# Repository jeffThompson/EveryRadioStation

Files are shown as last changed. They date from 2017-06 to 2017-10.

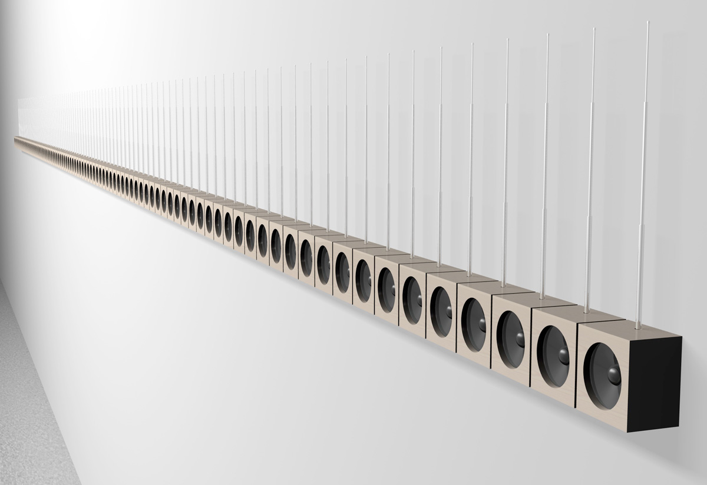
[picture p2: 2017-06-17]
Renderings/Mockup7-web.jpg

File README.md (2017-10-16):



# EVERY RADIO STATION

An installation of 95 software-defined FM radios, one for each station in the FM band, each playing simultaneously.

## CONTENTS  

* **CAD-Files:** PCB and lasercut files  
* **Datasheets:** For all important components in the piece  
* **Documentation:** Photo/video documentation  
* **EarlyVersions:** Roads-not-taken, broken things, and other early iterations  
* **Firmware:** Arduino firmware for communicating with the Si4703 radios over I2C  
* **Labels:** Stick-on labels for the back of the piece  
** LayoutDiagrams:** PDF and lasercut diagrams for placing all the parts  
* **Renderings:** Early renderings of how the piece would look and be displayed  
* **BOM:** List of materials used to build this piece  

Developed during a residency at [Wave Farm](https://wavefarm.org/) in Acra, New York, USA.

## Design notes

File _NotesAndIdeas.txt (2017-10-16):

NOTES && IDEAS

TODO

[ ] write up desc for website (already in db)

[X] design connections between boxes
[X] how to hang from wall?
[X] two power supplies, for stacked version?
	- or intermediary cord between them?
	- maybe could have separate box for power, make two
		- one with a single plug in the bottom
		- one with plug in bottom, connector on top?
[X] hole template for marking large speaker hole, smaller 
    mounting ones too
[X] figure out mounting holes for power supply
[X] how to mount PCBs to piece?
	- lasercut template
	- spraypaint to show area to use
	- foam tape to secure
	
- - -

95 total radios
- 12 per section, final section has 11
- covers 87.5–107.9
- should work everywhere except Japan and maybe Eastern Europe/Russia
- in Europe, bands may go by 100kHz inc instead of 200, so we might miss some
	- option in code to go odd (ie 99.1) or even (99.2) in case that's helpful

- - -

https://www.thingiverse.com/thing:683669/#comments

POWER SUPPLY – LS35 (3.3V)

L = live line in
N = neutral line in

should be at least 15mm (0.6") from anything on vent sides

- - -

https://learn.sparkfun.com/tutorials/si4703-fm-radio-receiver-hookup-guide

- - -

FM band from 87.5 - 107.9 MHz (in North America)
Separated by 2's on the odd numbers

87.5, 87.7, 87.9
- three stations

90.1, 90.3, 90.5, 90.7, 90.9
- five stations per block like this...

91, 92, 93, 94, 95, 96, 97, 98, 99, 100,
101, 102, 103, 104, 105, 106, 107
- 17 blocks of 5 = 85

Total number of possible FM radio stations:
3 + 5 + 85 = 93

+ #0
	0	875
	1	877
	2	879
	3	881
	4	883
	5	885
	6	887
	7	889

+ #1
	0	891
	1	893
	2	895
	3	897
	4	899
	5	901
	6	903
	7	905

+ #2
	0	907
	1	909
	2	911
	3	913
	4	915
	5	917
	6	919
	7	921

+ #3
	0	923
	1	925
	2	927
	3	929
	4	931
	5	933
	6	935
	7	937
	
+ #4
	0	939
	1	941
	2	943
	3	945
	4	947
	5	949
	6	951
	7	953

+ #5
	0	955
	1	957
	2	959
	3	961
	4	963
	5	965
	6	967
	7	969

+ #6
	0	971
	1	973
	2	975
	3	977
	4	979
	5	981
	6	983
	7	985

+ #7
	0	987
	1	989
	2	991
	3	993
	4	995
	5	997
	6	999
	7	1001

+ #8
	0	1003
	1	1005
	2	1007
	3	1009
	4	1011
	5	1013
	6	1015
	7	1017

+ #9
	0	1019
	1	1021
	2	1023
	3	1025
	4	1027
	5	1029
	6	1031
	7	1033
	0	1035
	1	1037

#10	
	2	1039
	3	1041
	4	1043
	5	1045
	6	1047
	7	1049
	0	1051
	1	1053

#11
	2	1055
	3	1057
	4	1059
	5	1061
	6	1063
	7	1065
	8	1067

oops
	7	1069
	0	1071
	1	1073
	2	1075
	3	1079

- - -

AM band from 535 - 1705 kHz (in North America)
Separated by 10's

535 (effectively 540), 550, 560, 570, 580, 590
- block of six stations

600, 700, 800, 900, 1000, 1100, 1200, 1300, 
1400, 1500, 1600
- 11 blocks of 10 stations = 1100

1705 (effectively (1700)
- last station

Total number of possible AM radio stations:
6 + 1100 + 1 = 1107

- - -

Total number of possible AM and FM radio stations in 
any given place in North America: 1,200

- https://www.sparkfun.com/products/12938
- http://www.silabs.com/Support%20Documents/TechnicalDocs/Si4831-35-B30.pdf
- possible SDR method: https://github.com/hpdvanwyk/fm-multimix
- https://github.com/kpreid/shinysdr

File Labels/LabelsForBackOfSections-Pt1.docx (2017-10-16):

Jeff Thompson Every Radio Station: Section 1 Wood, 95 FM radios, speakers, custom software 2017 Cleats: 27” between, 5” to next section (both on center) | | Jeff Thompson Every Radio Station: Section 2 Wood, 95 FM radios, speakers, custom software 2017 Cleats: 27” between, 5” to next section (both on center)
Jeff Thompson Every Radio Station: Section 3 Wood, 95 FM radios, speakers, custom software 2017 Cleats: 27” between, 5” to next section (both on center) | | Jeff Thompson Every Radio Station: Section 4 Wood, 95 FM radios, speakers, custom software 2017 Cleats: 27” between, 5” to next section (both on center)
Jeff Thompson Every Radio Station: Section 5 Wood, 95 FM radios, speakers, custom software 2017 Cleats: 27” between, 5” to next section (both on center) | | Jeff Thompson Every Radio Station: Section 6 Wood, 95 FM radios, speakers, custom software 2017 Cleats: 27” between, 5” to next section (both on center)

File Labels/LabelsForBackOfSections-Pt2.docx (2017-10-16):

Jeff Thompson Every Radio Station: Section 7 Wood, 95 FM radios, speakers, custom software 2017 Cleats: 27” between, 5” to next section (both on center) | | Jeff Thompson Every Radio Station: Section 8 Wood, 95 FM radios, speakers, custom software 2017 Cleats: 27” between, 5” to next section (both on center)
Jeff Thompson Every Radio Station: Section 9 Wood, 95 FM radios, speakers, custom software 2017 Cleats: 24” between, 5” to next section (both on center) | | Jeff Thompson Every Radio Station: Section 10 Wood, 95 FM radios, speakers, custom software 2017 Cleats: 27” between, 5” to next section (both on center)
Jeff Thompson Every Radio Station: Section 11 Wood, 95 FM radios, speakers, custom software 2017 Cleats: 27” between, 5” to next section (both on center) | | Jeff Thompson Every Radio Station: Section 0 Wood, 95 FM radios, speakers, custom software 2017 Cleats: 27” between, 5” to next section (both on center)

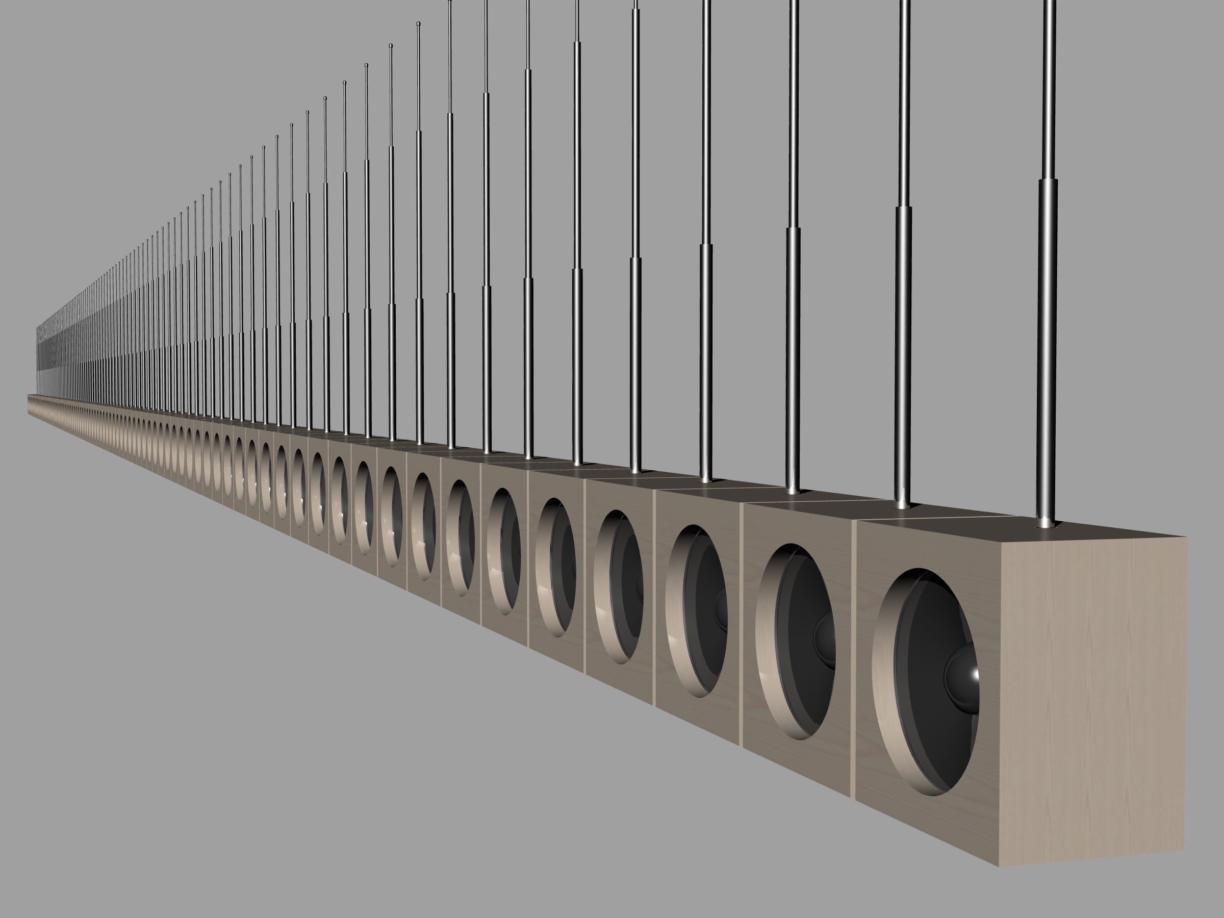
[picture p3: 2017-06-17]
Renderings/Mockup3.jpg

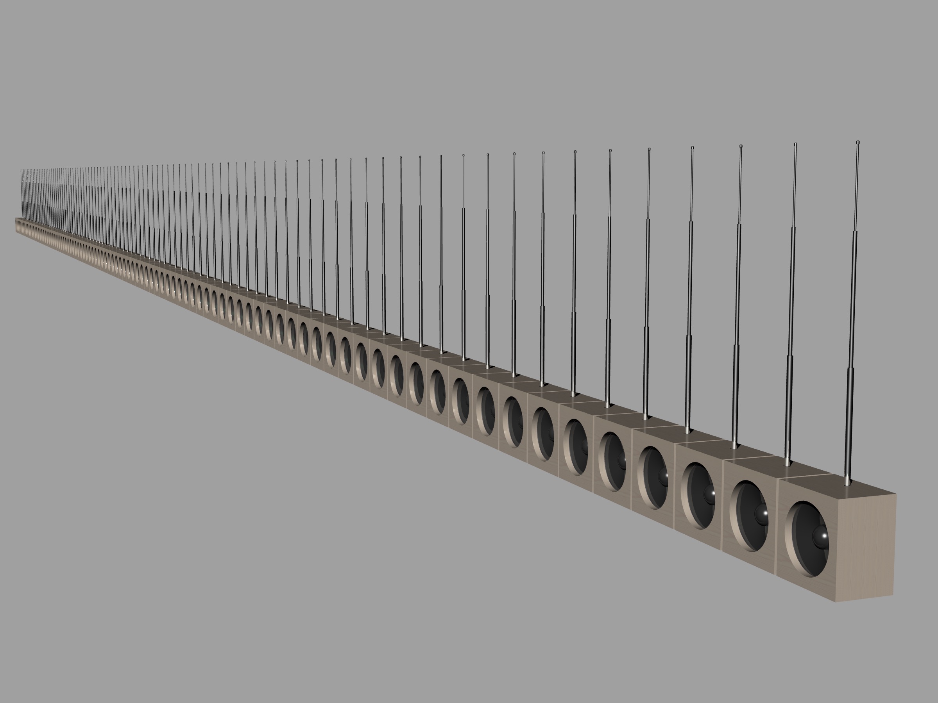
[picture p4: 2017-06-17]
Renderings/Mockup2.jpg

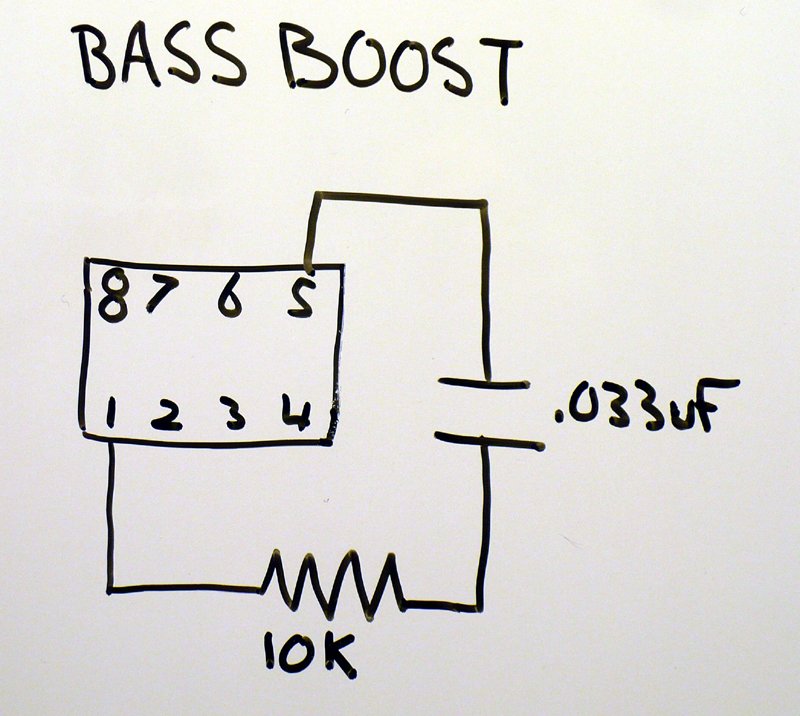
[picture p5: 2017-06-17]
EarlyVersions/LM386bassboost.jpg

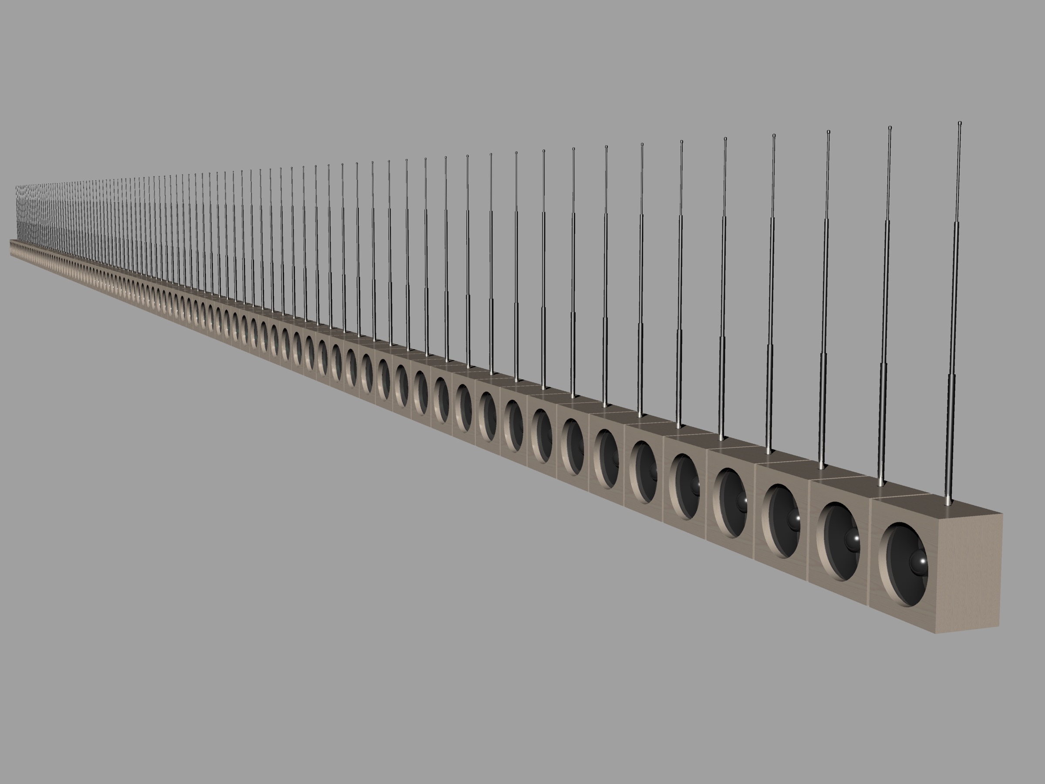
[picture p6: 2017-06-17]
Renderings/Mockup1.jpg

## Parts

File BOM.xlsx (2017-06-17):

EVERY RADIO STATION: BILL OF MATERIALS
DESCRIPTION | $ EA | QTY | $ TOTAL | VENDOR | URL
Arduino Pro Mini 3.3V | $9.95 | 8 | $79.60 | Adafruit | https://www.adafruit.com/product/2377
TCA9548 I2C multiplexer | $6.95 | 8 | $55.60 | Adafruit | https://www.adafruit.com/product/2717
Si4703 evaluation board (lot of 10x) | $31.00 | 10 | $310.00 | NewEgg | https://www.newegg.com/Product/Product.aspx?Item=9SIADD85RA6519&ignorebbr=1
6-32 x 3/4" bolts for mounting speakers (100/pack) | $7.25 | 4 | $29.00 | McMaster | https://www.mcmaster.com/#97763a328/=17yqzgn
6-32 nuts for speakers (100/pack) | $1.24 | 4 | $4.96 | McMaster | https://www.mcmaster.com/#90480a007/=17yr0pa
120/220VAC to 3.3VDC power supply | $32.22 | 1 | $32.22 | Mouser | http://www.mouser.com/ProductDetail/TDK-Lambda/LS35-33/
 |  | TOTAL | $511.38
PARTS ALREADY ON HAND
DESCRIPTION | $ EA | QTY | $ TOTAL | VENDOR | URL
Speaker | $10.00 | 100 | $1000.00 | Parts Express | https://www.parts-express.com/peerless-by-tymphany-tc9fd18-08-3-1-2-full-range-paper-cone-woofer--264-1062
CUSTOM-BUILT PARTS
DESCRIPTION | QTY | NOTES
3V/ground power bus PCBs | 8 | Milled or etched PCBs, Eagle and Gerber files in this repo
Wood boxes for radios | 93

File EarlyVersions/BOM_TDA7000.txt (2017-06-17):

RADIO PARTS

TDA7000 IC
http://www.futurlec.com/Philips/TDA7000pr.shtml

3.5-turn Variable Coil
http://electronics-diy.com/product_details.php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

Varicap Diode
http://electronics-diy.com/product_details.php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,%20BB205%29

- - - - - - - -

1nF (1000pF) - 1x
http://www.mouser.com/ProductDetail/Kemet/C315C102K1G5CA/?qs=sGAEpiMZZMuAYrNc52CMZKaako6zo7mHEYHIF7UlwRM%3d

2.2nF (2200pF) - 1x
http://www.mouser.com/ProductDetail/Kemet/C322C222J5G5CA7301/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

3.3nF (3300pF) - 2x
http://www.mouser.com/ProductDetail/Kemet/C320C332K5R5CA7303/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

10nF (0.01uF) - 1x
http://www.mouser.com/ProductDetail/Kemet/C317C103K5R5TA/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

22nF (0.022uF - 1x
http://www.mouser.com/ProductDetail/TDK/FK14X7R1H224K/?qs=sGAEpiMZZMuAYrNc52CMZGH05pWz8dc0d6NumRGlSWk%3d

100nF (0.1uF) - 3x
http://www.mouser.com/Search/ProductDetail.aspx?R=FK26X7R1E105Kvirtualkey52130000virtualkey810-FK26X7R1E105K

- - - - - - - -

150pF - 1x
http://www.mouser.com/Search/ProductDetail.aspx?R=C315C151J1G5TAvirtualkey64600000virtualkey80-C315C151J1G

180pF - 2x
http://www.mouser.com/ProductDetail/Vishay-BC-Components/K181J15C0GF53L2/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

220pF - 2x
http://www.mouser.com/ProductDetail/Vishay-BC-Components/K221J15C0GH5TL2/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

300pF - 2x
http://www.mouser.com/ProductDetail/Murata/RPE5C1H301J2P1A03B/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

- - - - - - - -

22k - 1x
http://www.mouser.com/ProductDetail/KOA-Speer/MF1-4DC2202F/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

100k - 1x
http://www.mouser.com/ProductDetail/Xicon/270-100K-RC/?qs=sGAEpiMZZMsPqMdJzcrNwlXWIga6NKq%2feGlftqSTssU%3d

100k pot - 1x
http://www.mouser.com/Search/ProductDetail.aspx?R=3362R-1-104LFvirtualkey65210000virtualkey652-3362R-1-104LF

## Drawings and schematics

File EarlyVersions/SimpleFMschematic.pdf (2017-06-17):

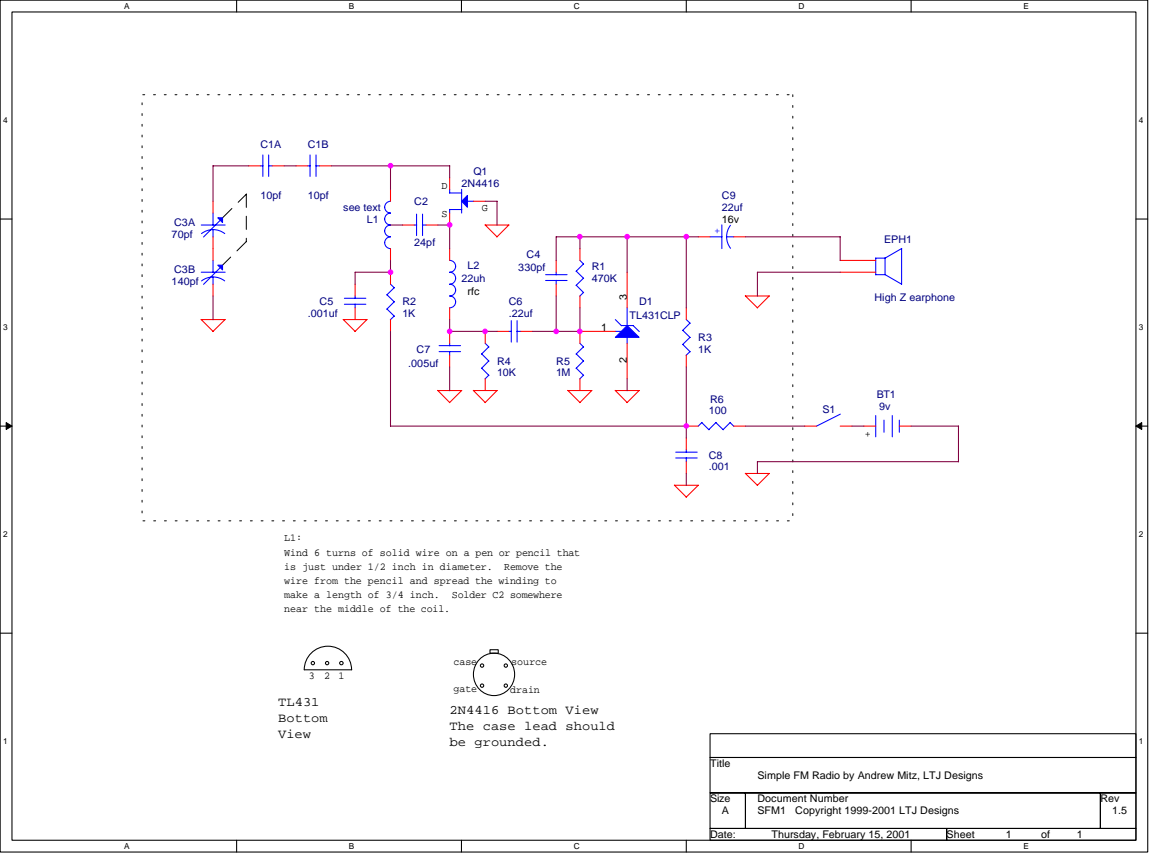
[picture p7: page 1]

10pf 10pf see text L1 | C2

is just under 1/2 inch in diameter. Remove the
wire from the pencil and spread the winding to
make a length of 3/4 inch. Solder C2 somewhere
near the middle of the coil.

gate
2N4416 Bottom View
The case lead should
be grounded.

Title Simple FM Radio by Andrew Mitz, LTJ Designs

Size A | Document Number SFM1 Copyright 1999-2001 LTJ Designs | | Rev 1.5

Date: Thursday, February 15, 2001 | | Sheet 1 of 1

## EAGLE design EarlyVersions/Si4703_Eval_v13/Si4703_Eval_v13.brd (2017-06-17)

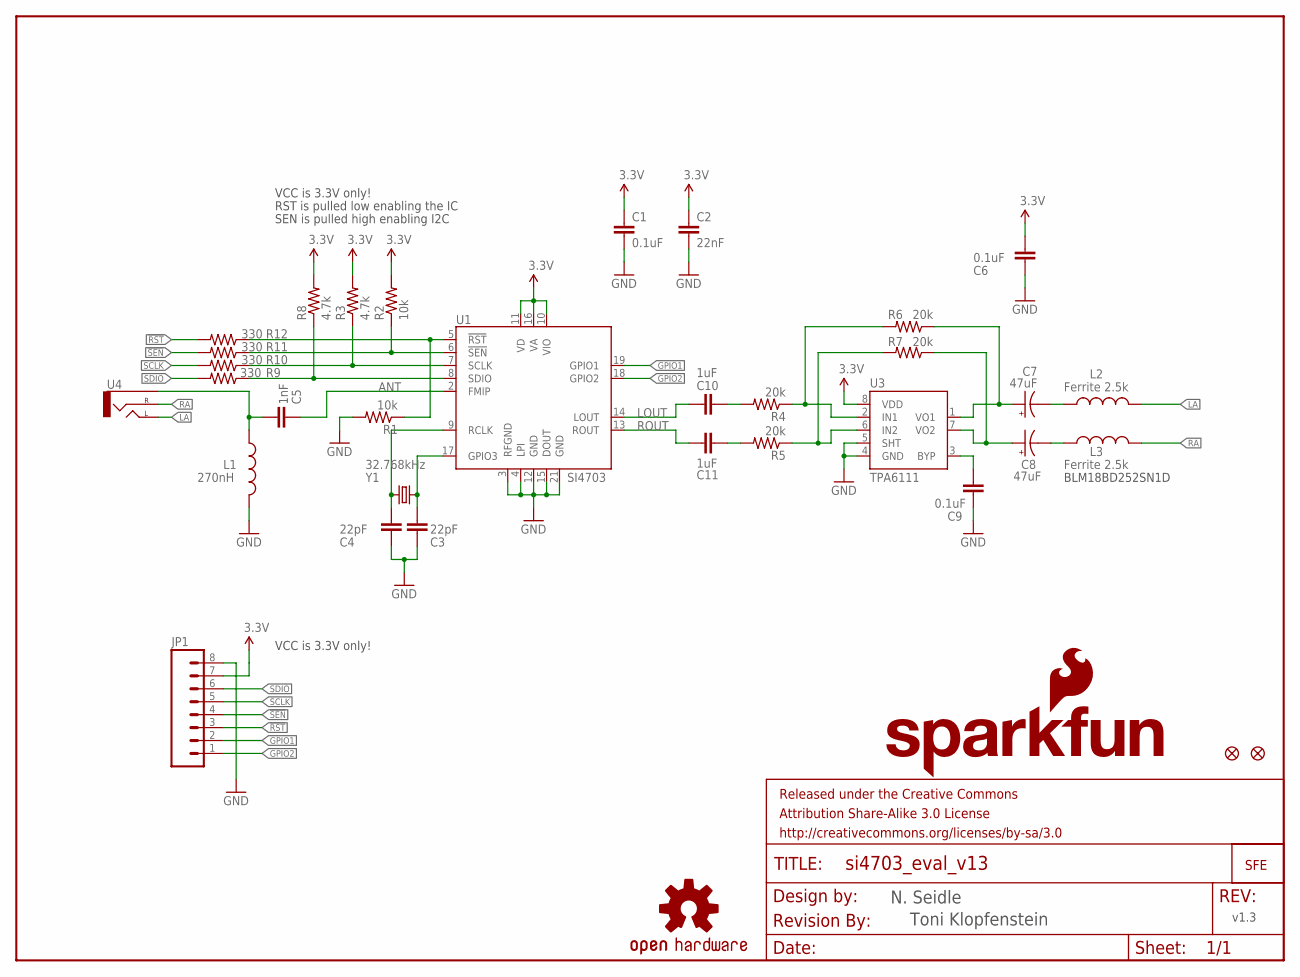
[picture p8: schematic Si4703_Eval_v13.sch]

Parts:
C1, C6, C9: 0.1uF; 0603-CAP
C2: 22nF; 0603-CAP
C3, C4: 22pF; 0603-CAP
C5: 1nF; 0603-CAP
C7, C8: 47uF; EIA3528
C10, C11: 1uF; 0603-CAP
FRAME2: FRAME-LETTER; CREATIVE_COMMONS
JP1: M08; 1X08
JP3: LOGO-SFESK; SFE-LOGO-FLAME
JP4, JP5: FIDUCIAL1X2; FIDUCIAL-1X2
L1: 270nH; 0603
L2, L3: Ferrite 2.5k; 0603
LOGO1: SFE_LOGO_NAME_FLAME.1_INCH; SFE_LOGO_NAME_FLAME_.1
LOGO2: OSHW-LOGOS; OSHW-LOGO-S
R1, R2: 10k; 0603-RES
R3, R8: 4.7k; 0603
R4, R5, R6, R7: 20k; 0603-RES
R9, R10, R11, R12: 330; 0603-RES
U1: SI4703; SI470X
U3: TPA6111; SO08-TIGHT
U4: AUDIO-JACKSMD2; AUDIO-JACK-3.5MM-SMD
U$1: REVISION
Y1: 32.768kHz; CRYSTAL-32KHZ-SMD

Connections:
3.3V: C1.1, C2.1, C6.2, JP1.7, R2.2, R3.2, R8.2, U1.10 (VIO), U1.11 (VD), U1.16 (VA), U3.8 (VDD)
!RST: JP1.3, R12.2
!RST-L: R1.1, R12.1, U1.5 (!RST)
!SEN: JP1.4, R11.2
!SEN-L: R2.1, R11.1, U1.6 (!SEN)
ANT: C5.1, U1.2 (FMIP)
GND: C1.2, C2.2, C3.1, C4.1, C6.1, C9.2, JP1.8, L1.2, R1.2, U1.3 (RFGND), U1.4 (LPI), U1.12 (GND), U1.15 (DOUT), U1.21 (GND), U3.4 (GND), U3.5 (SHT)
GPIO1: JP1.2, U1.19 (GPIO1)
GPIO2: JP1.1, U1.18 (GPIO2)
LA: L2.2, U4.TIP (LEFT)
LOUT: C10.1, U1.14 (LOUT)
unnamed: C4.2, U1.9 (RCLK), Y1.X2 (2)
unnamed: C3.2, U1.17 (GPIO3), Y1.X1 (1)
unnamed: C5.2, L1.1, U4.SLEEVE
unnamed: C7.C (-), L2.1
unnamed: C7.A (+), R6.1, U3.1 (VO1)
unnamed: C8.A (+), R7.1, U3.7 (VO2)
unnamed: C8.C (-), L3.1
unnamed: C9.1, U3.3 (BYP)
unnamed: R4.1, R6.2, U3.2 (IN1)
unnamed: R5.1, R7.2, U3.6 (IN2)
unnamed: C10.2, R4.2
unnamed: C11.2, R5.2
RA: L3.2, U4.RING (RIGHT)
ROUT: C11.1, U1.13 (ROUT)
SCLK: JP1.5, R10.2
SCLK-L: R3.1, R10.1, U1.7 (SCLK)
SDIO: JP1.6, R9.2
SDIO-L: R8.1, R9.1, U1.8 (SDIO)

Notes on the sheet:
VCC is 3.3V only!
N. Seidle
BLM18BD252SN1D
SEN is pulled high enabling I2C
RST is pulled low enabling the IC
v1.3
Toni Klopfenstein

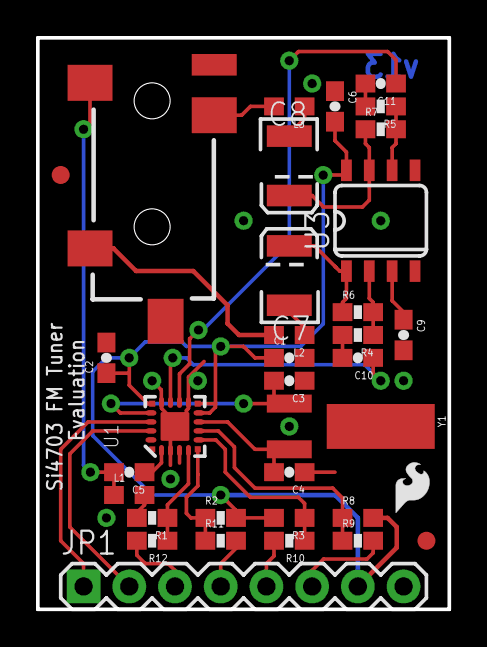
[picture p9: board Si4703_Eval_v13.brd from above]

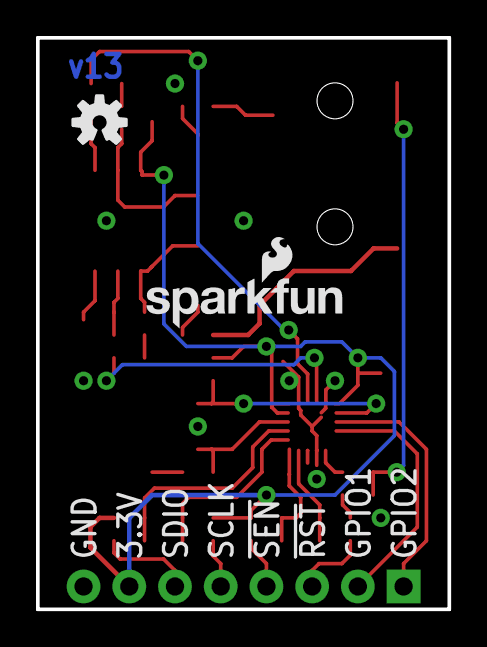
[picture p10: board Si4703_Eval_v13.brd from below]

Board: 2 copper layers, 22.9 x 31.8 mm, 38 parts (2 on the bottom side), 29 nets.

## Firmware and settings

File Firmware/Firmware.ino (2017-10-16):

#include <Si4703_Breakout.h>
#include <Wire.h>

/*
  EVERY RADIO STATION: FIRMWARE
  Jeff Thompson | 2017 | jeffreythompson.org

  Control software for "Every Radio Station". This project was
  supported by a residency at Wave Farm.

  NOTE ON FREQUENCIES
  Installations in the Americas, Europe, Australia, Africa, and Asia
  (except Japan) can all be accounted for in code below. Installations
  in Japan, some of Eastern Europe, and Russia may need manual changes
  to this code in order to work, or may not be possible at all.

  HARDWARE
  Setup for 8 radios per section, 12 of these setups total (the final
  section actually has only 7 radios, for a total of 95)

  + Custom-milled 3.3V and ground power bus PCB
  + Arduino Pro Mini 3.3V
  + TCDA9548 I2C multiplexer (Adafruit)
  + Si4973 FM radio breakout (Sparkfun)
  + Tymphany TC9FD18 speaker (Parts Express)

*/

const int whichSection = 9;       // which section of radios? (0–11)

const boolean debug =    true;    // debug over serial? (turn off for final install)

const int SDIO =         A4;      // I2C pins on Arduino
const int SCLK =         A5;

// all the radios
// first value is the digital pin that radio's reset
// pin is connected to (must be unique for each radio)
// backwards since I wired them wrong :(
Si4703_Breakout radios[8] = {
  Si4703_Breakout(2, SDIO, SCLK),
  Si4703_Breakout(3, SDIO, SCLK),
  Si4703_Breakout(4, SDIO, SCLK),
  Si4703_Breakout(5, SDIO, SCLK),
  Si4703_Breakout(6, SDIO, SCLK),
  Si4703_Breakout(7, SDIO, SCLK),
  Si4703_Breakout(8, SDIO, SCLK),
  Si4703_Breakout(9, SDIO, SCLK)
};

// optional: use pre-determined volumes for each radio
// can be used to lessen the volume of really loud stations
// values in adjustment array should be -15 – +15
const boolean useVolumeAdjustments = false;
const int volumeAdjustments[8] = {
  0, 0, 0, 0, 0, 0, 0, 0
};

// jumper pins to set volume
// if neither connected, will be set to max volume
// via: http://forum.arduino.cc/index.php?topic=20131.msg148010#msg148010
const int volTestPin =     11;      // pin to test against, in between the low and medium pins
                                    // (means you can't accidentally connect it wrong)
const int lowVolPin =      10;      // if connected, set to low volume
const int medVolPin =      12;      // ditto to medium volume

const boolean tuneEvenStations = false;   // tune even-numbered stations (ex 88.8)
                                          // really only for European installs, leave alone otherwise

const boolean delayStart = true;          // delay start so they all come on in one nice row?
                                          // super not-necessary, but fun
const long startupDelay =  5600;          // millis to delay for each set to begin


void setup() {

  if (debug) {
    Serial.begin(9600);
    Serial.println("\n\n\n\n\n\n\n\n\n\n\n\n\n\n\n\n\n");
    Serial.println("EVERY RADIO STATION: INITIALIZING");
    Serial.print("Section:       ");
    Serial.println(whichSection);
  }

  // find starting channel for this section
  // is a 3-digit integer value (991 = 99.1FM)
  // can also account for running up even-numbered stations (ie 88.8) if desired
  int startChannel = 879 + ((whichSection) * 16);
  if (tuneEvenStations) startChannel = 876 + ((whichSection) * 16);
  if (debug) {
    Serial.print("Start channel: ");
    Serial.println(startChannel);
  }

  // set # of radios, depending on which section we're in
  int numRadios = 8;            // most sections have 8 radios
  if (whichSection == 11)  {
    numRadios = 7;              // final section only has 7
  }
  if (debug) {
    Serial.print("# radios:      ");
    Serial.println(numRadios);
  }

  // setup for volume jumper pins
  // set volume accordingly (range of 0–15)
  pinMode(volTestPin, OUTPUT);
  digitalWrite(volTestPin, LOW);      // set LOW, if other pins go LOW too we know they're connected
  pinMode(lowVolPin, INPUT_PULLUP);   // enable using internal pullup resistor
  pinMode(medVolPin, INPUT_PULLUP);
  int volume = checkVolumeJumpers();
  if (debug) {
    Serial.print("Volume:        ");
    Serial.println(volume);
    Serial.println("");
  }

  // delay starting, so they all come on in a nice long row
  int startTime = millis();
  if (delayStart) {
    long delayTime = whichSection * startupDelay;
    Serial.print("(Delaying startup ");
    Serial.print(delayTime);
    Serial.println(" ms...)");
    delay(delayTime);
    Serial.println("");
  }

  // start up all the radios in this section
  if (debug) {
    Serial.println("Starting radios...");
    if (useVolumeAdjustments) {
      Serial.println("(using individual volume adjustments)");
    }
  }
  for (int i=numRadios-1; i>=0; i-=1) {       // backwards, since I wired them wrong :(
    selectOutput(i);                          // select I2C output channel
    radios[i].powerOn();                      // turn it on
    int channel = startChannel + (i * 2);     // FM moves by 2, after 99.5 is 99.7, etc
    if (debug) {
      Serial.print("- freq: ");
      Serial.print(channel);
    }
    radios[i].setChannel(channel);
    
    // set volume, either to value set by jumper
    // or adjusted individually
    int vol = volume;
    if (useVolumeAdjustments) {
      vol += volumeAdjustments[i];
      vol = constrain(vol, 0, 15);
    }
    radios[i].setVolume(vol);
    if (debug) {
      Serial.print(", vol: ");
      Serial.println(vol);
    }
  }

  // that's it
  if (debug) {
    Serial.println("\nALL READY!");
    Serial.print("(startup time = ");
    Serial.print(millis() - startTime);
    Serial.println(")");

  }
}


void loop() {
  // nothing here
}


// test if any of the volume jumpers are connected
// return a new volume (0–15)
int checkVolumeJumpers() {
  if (digitalRead(lowVolPin) == LOW) {
    return 5;
  }
  else if (digitalRead(medVolPin) == LOW) {
    return 10;
  }
  return 15;
}


// function to select I2C output channel on TCA9548
void selectOutput(uint8_t i) {
  if (i > 7) return;
  Wire.beginTransmission(0x70);
  Wire.write(1 << i);
  Wire.endTransmission();
}

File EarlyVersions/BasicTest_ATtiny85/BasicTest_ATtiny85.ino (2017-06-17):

/*
BASIC TEST
Jeff Thompson | 2017 | jeffreythompson.org

1.8-2.7k pullup instead

Test code for using the Si4703 FM radio breakout with
ATtiny chip. This example is intended for ATtiny85, so
you may have to tweak your SDIO and SCLK pins, depending
on what chip you use.

REQUIRED LIBRARIES
Requires the TinyWireM library from Adafruit, which lets
you use I2C on ATtiny chips:
https://github.com/adafruit/TinyWireM

IC2
+ Data connection = SDA
    Should be on pin PB0, which is pin #5 on the ATtiny85, aka D0
+ Clock connection = SCK
    Should be on pin PB2, which is pin #7, aka D2

HOOKUP
Note: you must (MUST!) have pullup resistors on the SDA
and SCK lines, otherwise you will have problems, Sparkfun
suggests a 4.7k for each, like so:

    D0                  D2
    |   4.7k            |   4.7k
    +---[[[[---> 3V     +---[[[[---> 3V
    |                   |
   SDA                 SCK

Connect the rest:
+ VCC to your 3V supply, and out to the Si4703
+ GND to your supply and the radio
+ reset pin from D1 to the radio

MORE DETAILS ON ATTINY85
For more info on hooking up and using the ATtiny85
+ http://highlowtech.org/?p=1695
+ https://32414320wji53mwwch1u68ce-wpengine.netdna-ssl.com/wp-content/
  uploads/2011/05/Attiny-Master.gif
 
*/

#include <TinyWireM.h>
#include <Si4703_ATtiny.h>

//#define GPIO_ADDR 0x3F


int SDA =   0;       // I2C data pin on ATtiny85 (pin 
int SCK =   2;       // I2C clock pin on ATtiny85
int reset = 1;       // can probably be any digital pin

Si4703_ATtiny radio(reset, SDA, SCK);


void setup() {
  TinyWireM.begin();    // need this?
  
  // turn on radio
  // (creates connection with device)
  radio.powerOn();
//
//  // set a channel
//  // should be a three-digit integer
//  // for the station's frequency
//  // (ie 93.7FM = 937)
  radio.setChannel(937);
}

void loop() {
  radio.setVolume(15);
  delay(1000);
  radio.setVolume(0);
  delay(1000);
}


//
//  // play the radio for 5 seconds
//  delay(5000);
//
//  // seek channels up five times,
//  // listen for a second
//  for (int i=0; i<5; i++) {
//    radio.seekUp();
//    delay(1000);
//  }
//
//  // fade out volume programatically
//  for (int i=15; i>0; i-=1) {
//    radio.setVolume(i);
//    delay(200);
//  }
//}


//void loop() {
//  // nothing here :)
//}

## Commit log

2017-06-23 Updated wiring and layout diagrams
2017-10-16 Lasercut end caps
2017-10-16 Moved to a folder for all CAD files
    [PowerBus.brd, PowerBus.sch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]

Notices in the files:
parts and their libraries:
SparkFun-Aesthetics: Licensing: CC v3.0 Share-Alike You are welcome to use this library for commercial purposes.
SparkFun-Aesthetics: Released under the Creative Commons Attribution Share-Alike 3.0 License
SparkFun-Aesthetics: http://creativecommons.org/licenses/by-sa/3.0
